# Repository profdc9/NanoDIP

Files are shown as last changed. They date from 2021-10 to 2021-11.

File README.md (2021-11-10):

# Nano-like PCB using ATMEGA328P

Because of the 2021 chip shortage, any chip, especially SMT, is not available.  However, some ATMEGA328Ps can still be had or removed from older devices such as Arduino Uno.

I made a simple PCB that has the Arduino Nano pinout that takes a ATMEGA328P.  It connects to a serial port TTL device, using the DTR line for reset, and can be programmed using the Arduino IDE.  A cheap serial TTL converter is a CP2102 or CP2104 device.

ADC6 and ADC7 are not available because they are not exposed on the ATMEGA328P.

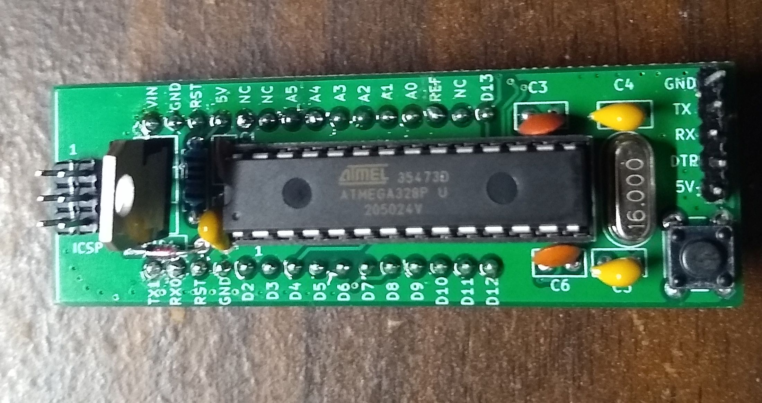
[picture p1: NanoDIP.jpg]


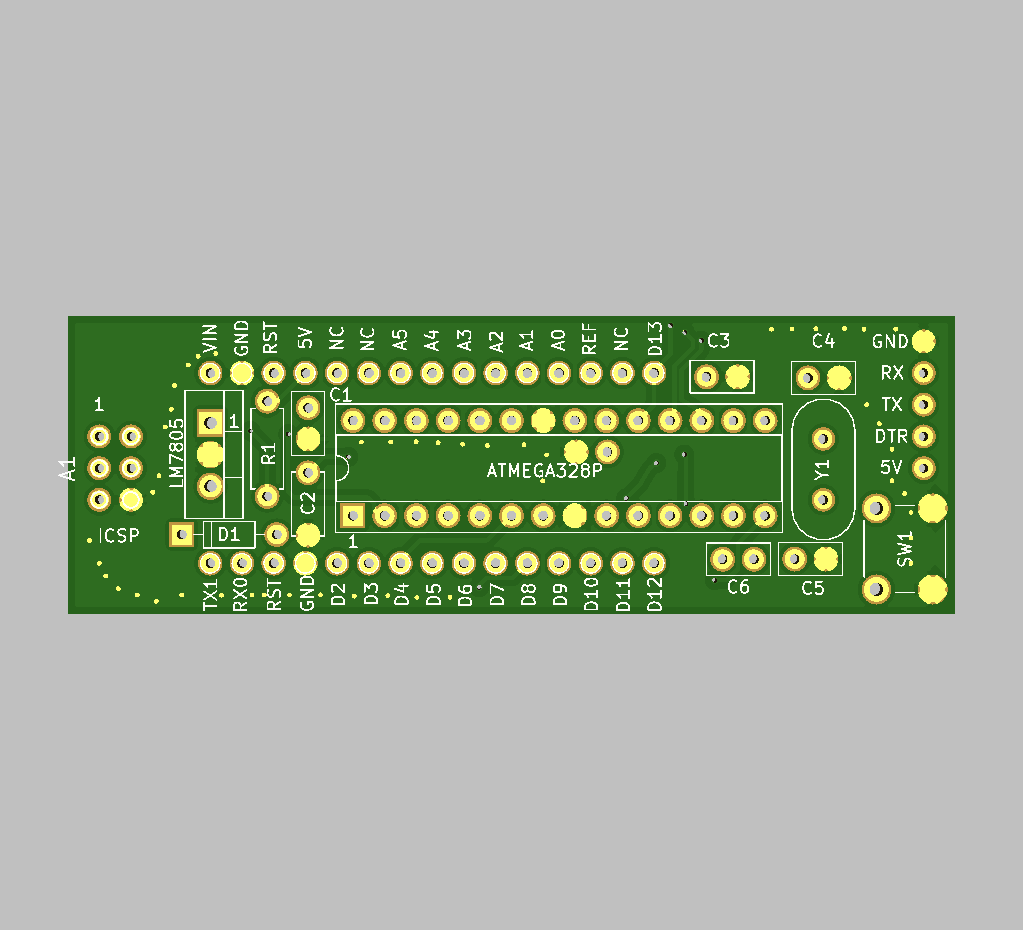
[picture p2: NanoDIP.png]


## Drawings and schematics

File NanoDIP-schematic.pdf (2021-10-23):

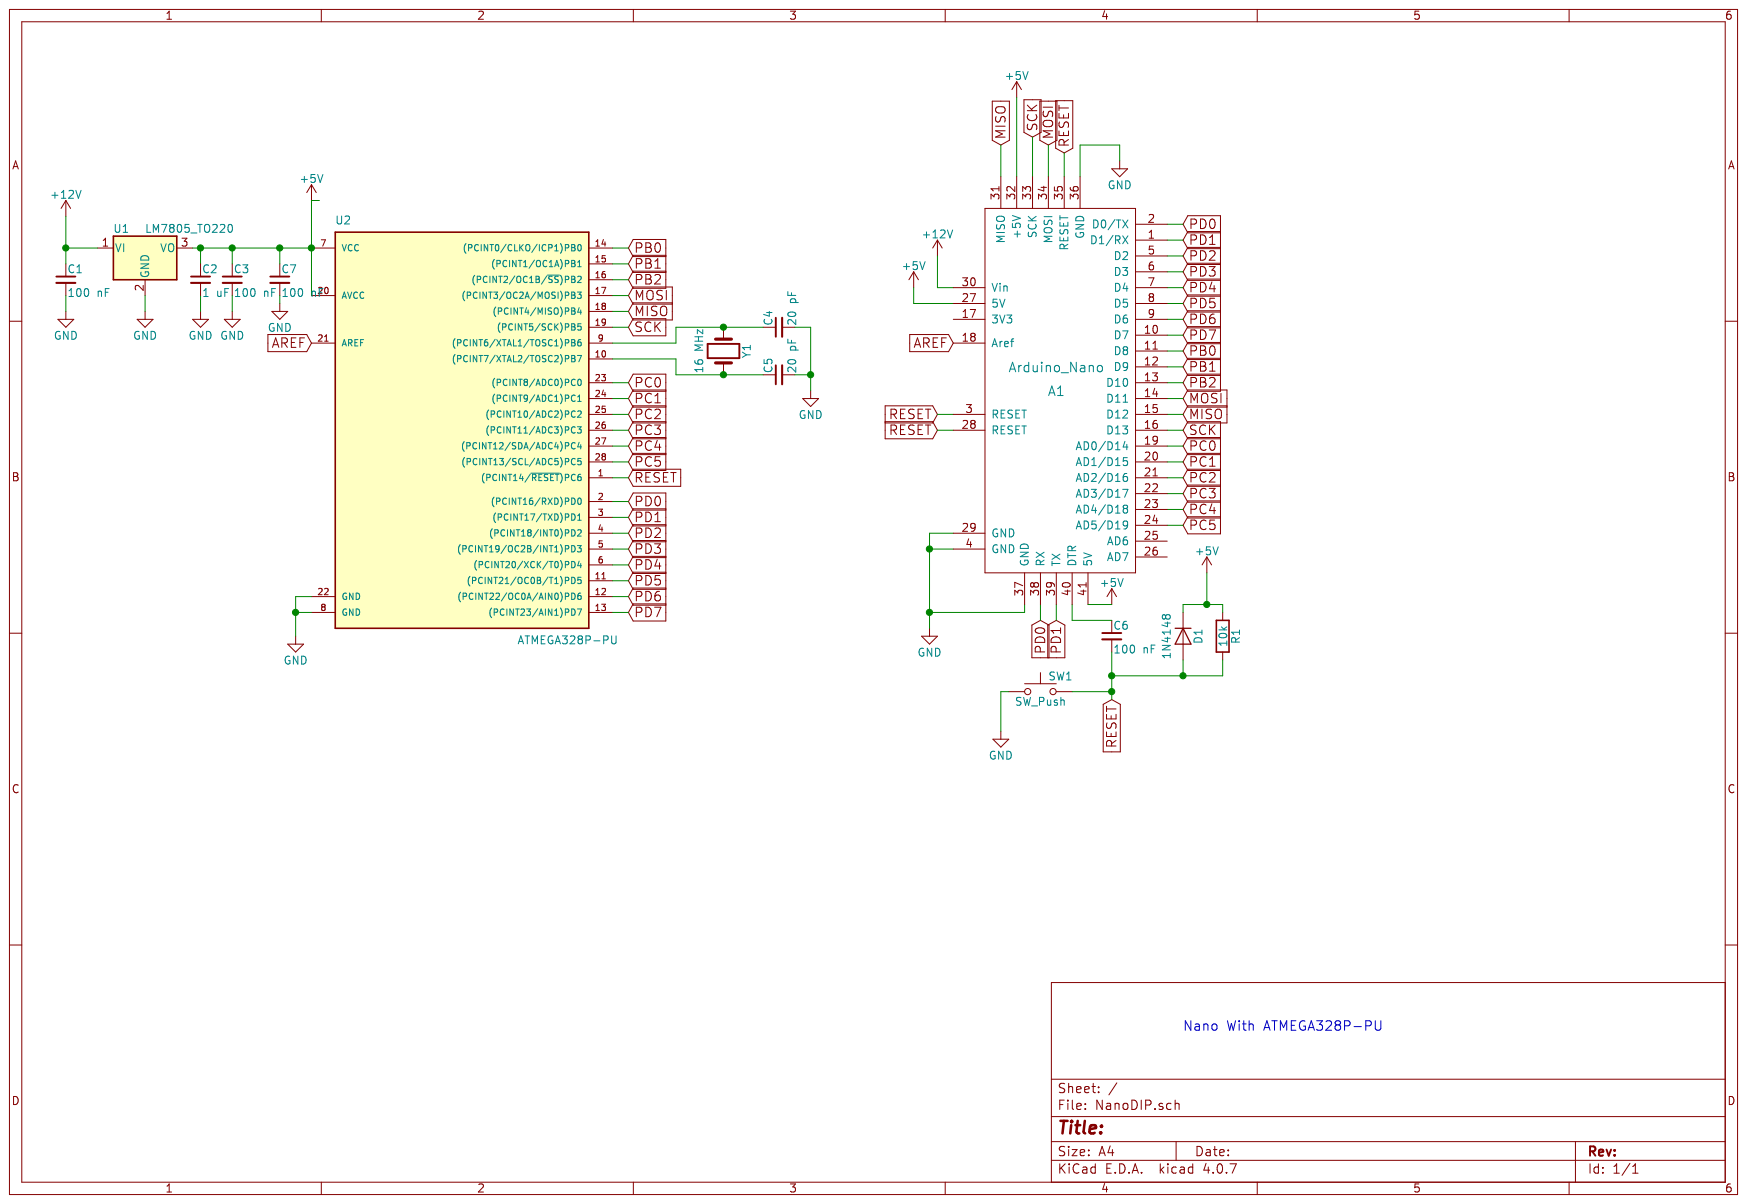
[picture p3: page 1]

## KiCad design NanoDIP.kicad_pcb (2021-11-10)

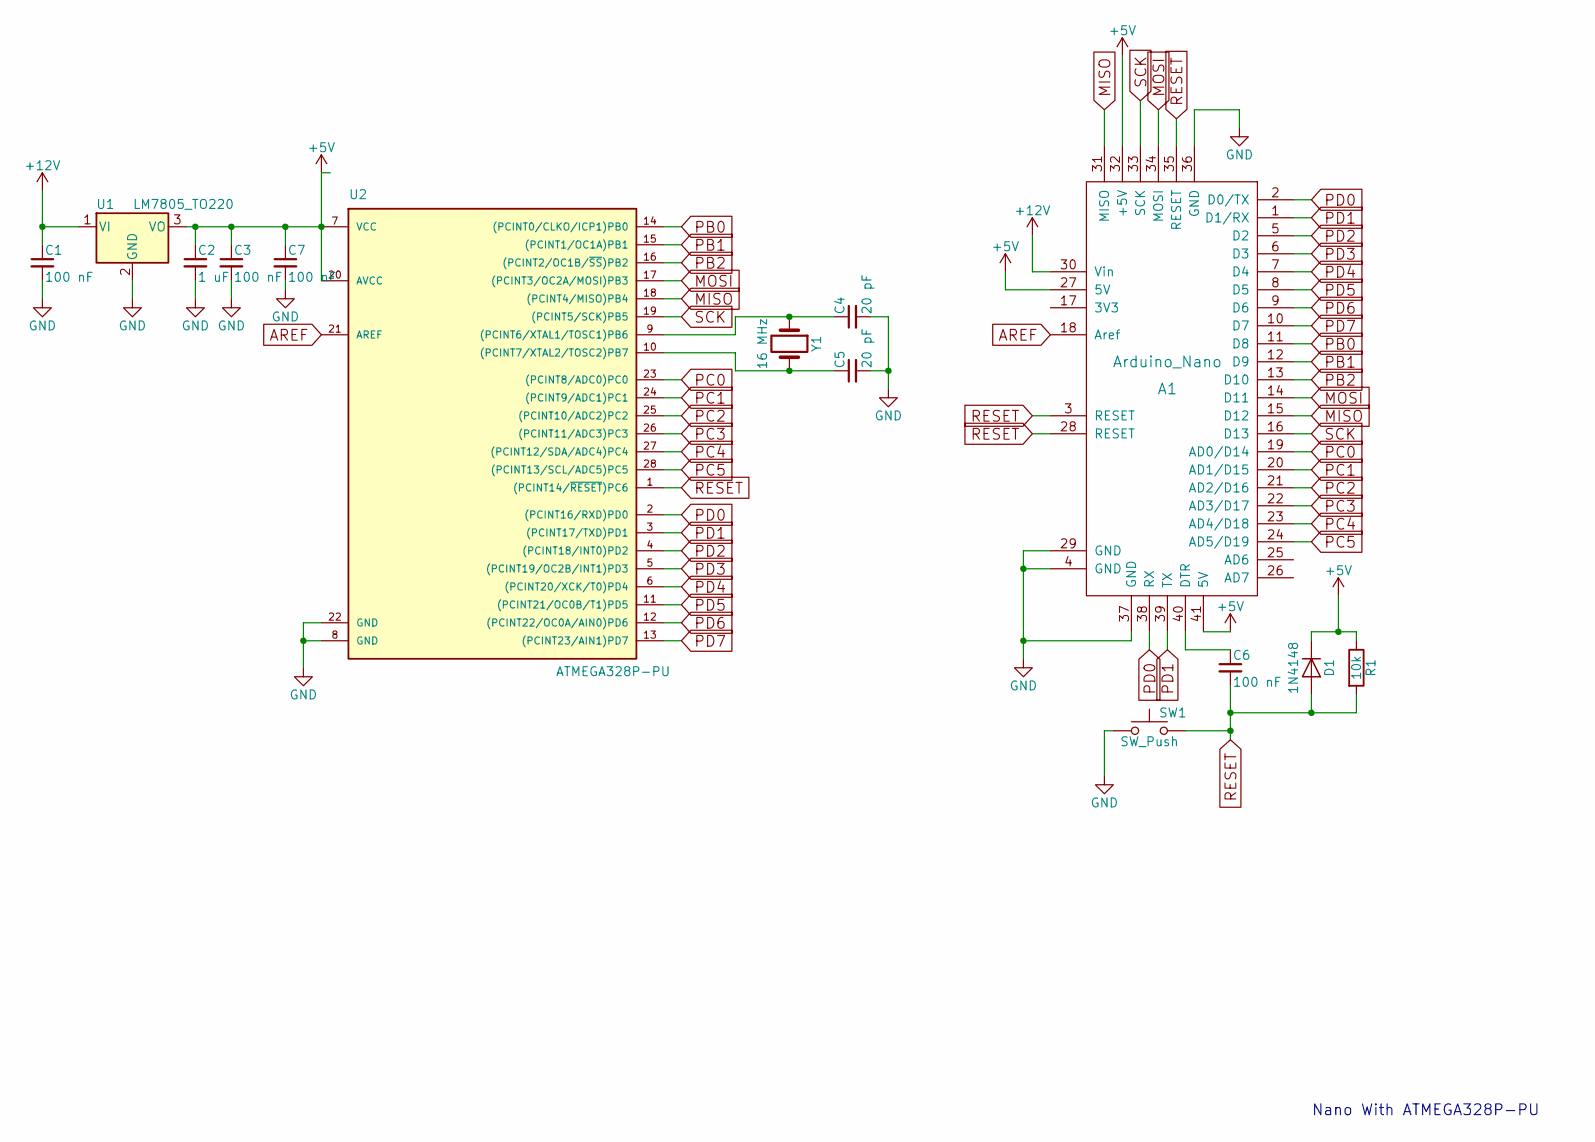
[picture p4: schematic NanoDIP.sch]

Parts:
A1: Arduino_Nano
C1, C3, C6, C7: 100 nF; C_Disc_D5.0mm_W2.5mm_P2.50mm
C2: 1 uF; C_Disc_D5.0mm_W2.5mm_P5.00mm
C4, C5: 20 pF; C_Disc_D5.0mm_W2.5mm_P2.50mm
D1: 1N4148; D_DO-35_SOD27_P7.62mm_Horizontal
R1: 10k; R_Axial_DIN0207_L6.3mm_D2.5mm_P7.62mm_Horizontal
SW1: SW_Push; SW_PUSH_6mm
U1: LM7805_TO220; TO-220-3_Vertical
U2: ATMEGA328P-PU; DIP-28_W7.62mm_Socket
Y1: 16 MHz; Crystal_HC49-U_Vertical

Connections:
+5V: A1.27 (5V), A1.32 (+5V), A1.41 (5V), C2.1, C3.1, C7.1, D1.1 (K), R1.1, U1.3 (VO), U2.7 (VCC), U2.20 (AVCC)
+12V: A1.30 (Vin), C1.1, U1.1 (VI)
AREF: A1.18 (Aref), U2.21 (AREF)
GND: A1.4 (GND), A1.29 (GND), A1.36 (GND), A1.37 (GND), C1.2, C2.2, C3.2, C4.2, C5.2, C7.2, SW1.1, U1.2 (GND), U2.8 (GND), U2.22 (GND)
MISO: A1.15 (D12), A1.31 (MISO), U2.18 ((PCINT4/MISO)PB4)
MOSI: A1.14 (D11), A1.34 (MOSI), U2.17 ((PCINT3/OC2A/MOSI)PB3)
unnamed: A1.40 (DTR), C6.1
unnamed: C4.1, U2.9 ((PCINT6/XTAL1/TOSC1)PB6), Y1.1
unnamed: C5.1, U2.10 ((PCINT7/XTAL2/TOSC2)PB7), Y1.2
PB0: A1.11 (D8), U2.14 ((PCINT0/CLKO/ICP1)PB0)
PB1: A1.12 (D9), U2.15 ((PCINT1/OC1A)PB1)
PB2: A1.13 (D10), U2.16 ((PCINT2/OC1B/~SS~)PB2)
PC0: A1.19 (AD0/D14), U2.23 ((PCINT8/ADC0)PC0)
PC1: A1.20 (AD1/D15), U2.24 ((PCINT9/ADC1)PC1)
PC2: A1.21 (AD2/D16), U2.25 ((PCINT10/ADC2)PC2)
PC3: A1.22 (AD3/D17), U2.26 ((PCINT11/ADC3)PC3)
PC4: A1.23 (AD4/D18), U2.27 ((PCINT12/SDA/ADC4)PC4)
PC5: A1.24 (AD5/D19), U2.28 ((PCINT13/SCL/ADC5)PC5)
PD0: A1.2 (D0/TX), A1.38 (RX), U2.2 ((PCINT16/RXD)PD0)
PD1: A1.1 (D1/RX), A1.39 (TX), U2.3 ((PCINT17/TXD)PD1)
PD2: A1.5 (D2), U2.4 ((PCINT18/INT0)PD2)
PD3: A1.6 (D3), U2.5 ((PCINT19/OC2B/INT1)PD3)
PD4: A1.7 (D4), U2.6 ((PCINT20/XCK/T0)PD4)
PD5: A1.8 (D5), U2.11 ((PCINT21/OC0B/T1)PD5)
PD6: A1.9 (D6), U2.12 ((PCINT22/OC0A/AIN0)PD6)
PD7: A1.10 (D7), U2.13 ((PCINT23/AIN1)PD7)
RESET: A1.3 (RESET), A1.28 (RESET), A1.35 (RESET), C6.2, D1.2 (A), R1.2, SW1.2, U2.1 ((PCINT14/~RESET~)PC6)
SCK: A1.16 (D13), A1.33 (SCK), U2.19 ((PCINT5/SCK)PB5)

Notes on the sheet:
Nano With ATMEGA328P-PU

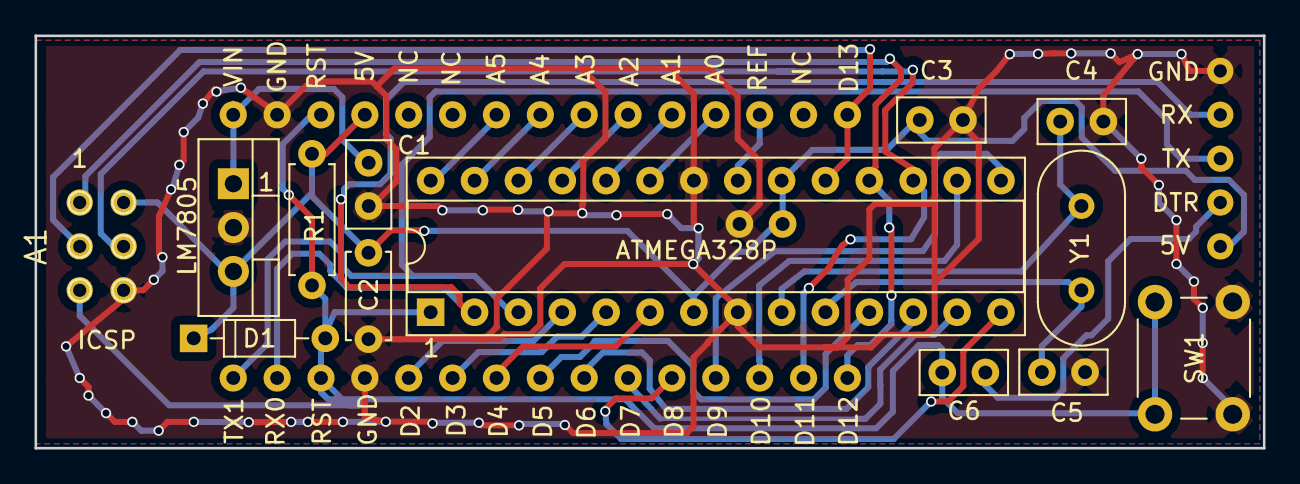
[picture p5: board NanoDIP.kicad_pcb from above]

Board: 2 copper layers, 71.1 x 23.9 mm, 14 parts (1 on the bottom side), 28 nets.

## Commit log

2021-10-18 Added pin labels
    [NanoDIP.kicad_pcb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]
2021-10-18 Added layers, turned around some labels
    [NanoDIP-B.Cu.gbr, NanoDIP-B.Mask.gbr, NanoDIP-B.SilkS.gbr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]
2021-10-19 Added 5V pin to program header
    [NanoDIP-B.Cu.gbr, NanoDIP-B.Mask.gbr, NanoDIP-B.SilkS.gbr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]
2021-10-23 JLCPCB order 2021-10-22
    [NanoDIP-B.Cu.gbr, NanoDIP-B.Mask.gbr, NanoDIP-B.SilkS.gbr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]
2021-11-10 Fixed RX/TX on pins
    [NanoDIP-B.Cu.gbr, NanoDIP-B.Mask.gbr, NanoDIP-B.SilkS.gbr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]
